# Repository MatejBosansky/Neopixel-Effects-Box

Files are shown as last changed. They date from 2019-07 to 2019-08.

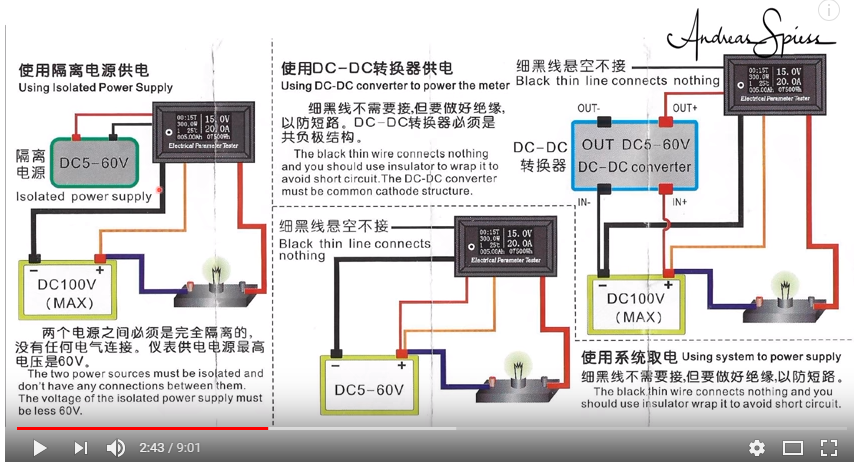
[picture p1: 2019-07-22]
docs/voltmeter wiring.bmp

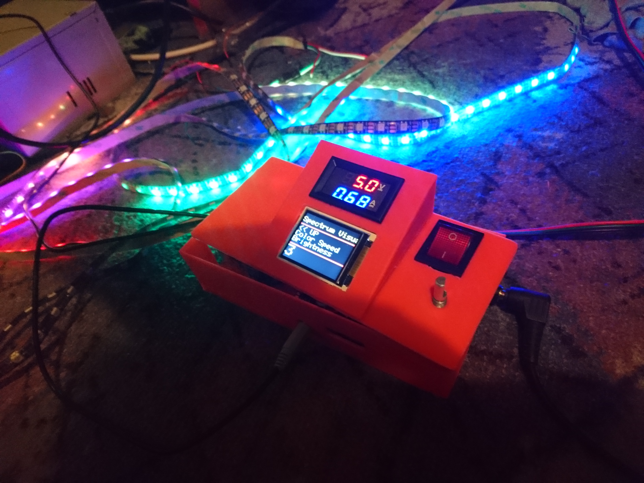
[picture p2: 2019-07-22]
docs/photos/image-20180716_222726.jpg

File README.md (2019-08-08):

# Neopixel Effects Box
Control predefined effects of your attached neopixel(ws2812b) led strip. To get brief overview how it looks like and what do you need, check:
- [Wiring scheme](https://github.com/MatejBosansky/Neopixel-Effects-Box/blob/master/docs/Scheme_bb.pdf).
- Video:

Youtube Video (http://www.youtube.com/watch?v=JeZSuh0Q6hs "Youtube Video")

## Features
- Power supply can be provided via any standard DC adapter like laptop charger with output rating 4-32V. 
- Configurable length of neopixel strip.
- Predefined 4 effects including sound spectrum visualizer based on your audio input.
- Control current effect and its properties with rotary encoder and LCD display.
- Possible to add your another effects - check notes.

## Hardware
I prepared shopping list for 2 aliexpress sellers to not overload your local post service.
Additionally to soldering iron, AC to DC adapter and neopixel strip you will need:

Basic components - This components you need:
- [Wemos D1 Mini ESP8266 Development board](http://www.aliexpress.com/item/32674463823.html).
- [DC-DC Step down converter with proper current rating](https://www.aliexpress.com/item/32821840536.html). Output DC must be adjustable to 5V.
- [ST7735S TFT LCD Display module](http://www.aliexpress.com/item/2055099048.html).
- [Rotary encoder](http://www.aliexpress.com/item/32224563961.html).
- [Mini digital voltmeter](http://www.aliexpress.com/item/32813014220.html).
- [Logic level converter](http://www.aliexpress.com/item/32216841860.html).
- [Audio female 3.5 connector](http://s.click.aliexpress.com/e/cAcySBSY).
- 1000uF +6.3V capacitor.
- 2x 1k Ohm resistor.

This components can be different if you design your own wiring and box.
- [Cable terminal](http://www.aliexpress.com/item/32815936999.html).
- [DC female connector](http://www.aliexpress.com/item/32829667875.html). Choose correct one based on your adapters male connector.
- [Switch](http://s.click.aliexpress.com/e/cFFxSPNA). Must be capable to handle max input current for strip.
- [Prototyping board](http://www.aliexpress.com/item/32224138773.html). 
- Fuse with proper rating.
- Wires.
- 3D printed BOX - check model in repository. This model is designed for components suggested in description.

## Notes
- Take in mind, that one ws2812b pixel can draw 60mA when is fully loaded (brightest white color). Multiply this value by count of your pixels and you have max possible power rating for your components like DC-DC converter, AC-DC adapter, wires, fuse, button.... But in reality real peak consuption for default effects is max 1/4 of this value.
- Recommending in code to define around 70% of max brightness - no too much noticable difference in brightness but significantly less power consuption.
- Code has been initialy developed in original Arduino IDE divided into multiple *ino files. In order to make quick migration to PlatformIO I needed to merge all files content into one main.cpp file.
- If you want to add your own effect, search `//**` code marks to go through guide inside the code.
- Check photos in docs folder to see parts layout on prototype board.
- **Must have project for every makers party!**

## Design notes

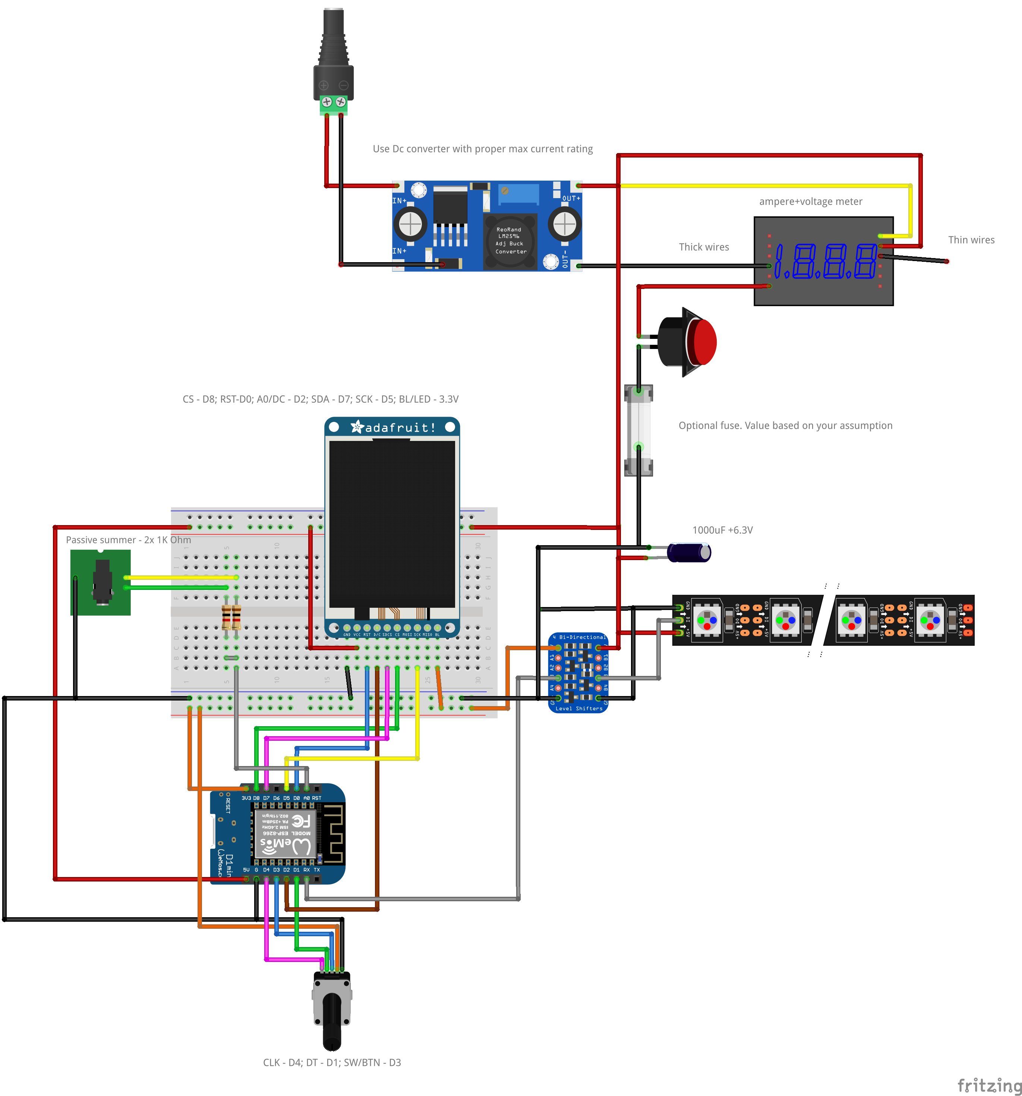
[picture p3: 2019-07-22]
docs/Scheme_bb.png

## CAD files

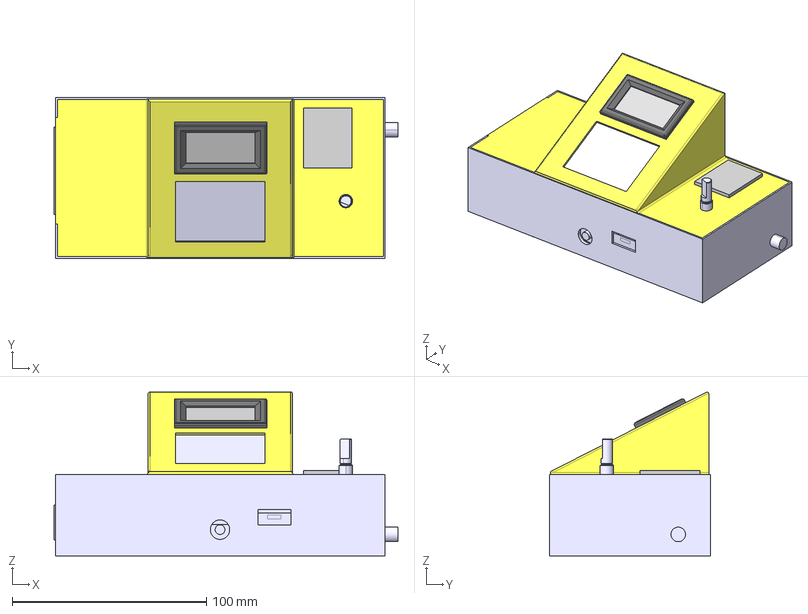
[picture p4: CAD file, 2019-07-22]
Box 3D model/Led Box assy.stp
177.3 x 82.9 x 84.4 mm
Button 20A
DC-DC 15A converter
rotary encoder_chesr_2013_AllCATPart
ST7733
Dc plug
Board
Bottom box
Box top
Mini DC 100V 10A Digital Voltmeter Ammeter v2

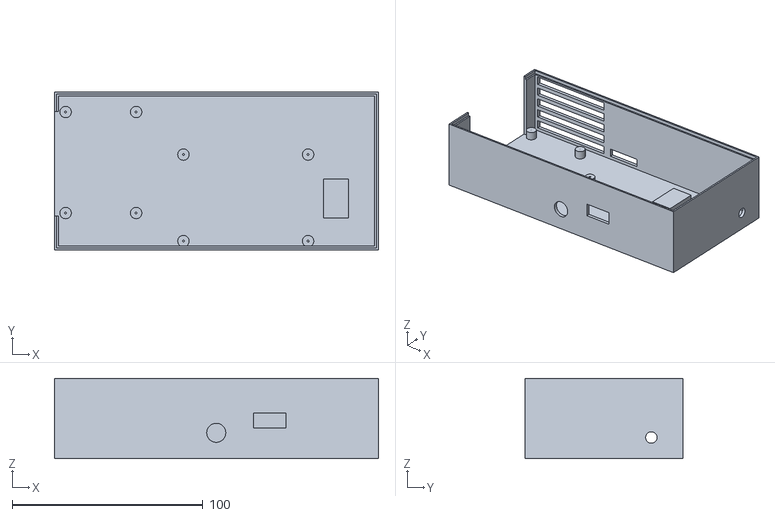
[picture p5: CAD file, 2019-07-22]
Box 3D model/Bottom Box.stl
170.0 x 82.9 x 42.0

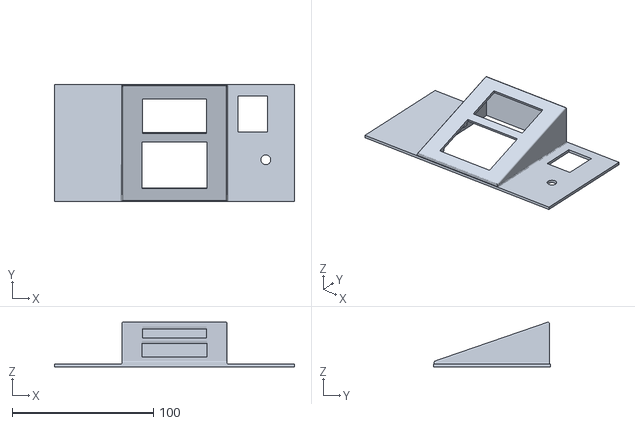
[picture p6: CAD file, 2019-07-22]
Box 3D model/Box top.stl
170.0 x 82.9 x 31.6

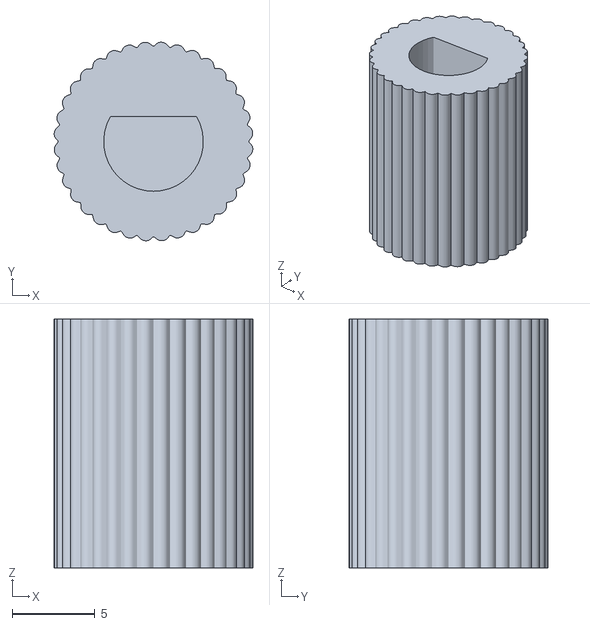
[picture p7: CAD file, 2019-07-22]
Box 3D model/Knob.stl
12.0 x 12.0 x 15.0

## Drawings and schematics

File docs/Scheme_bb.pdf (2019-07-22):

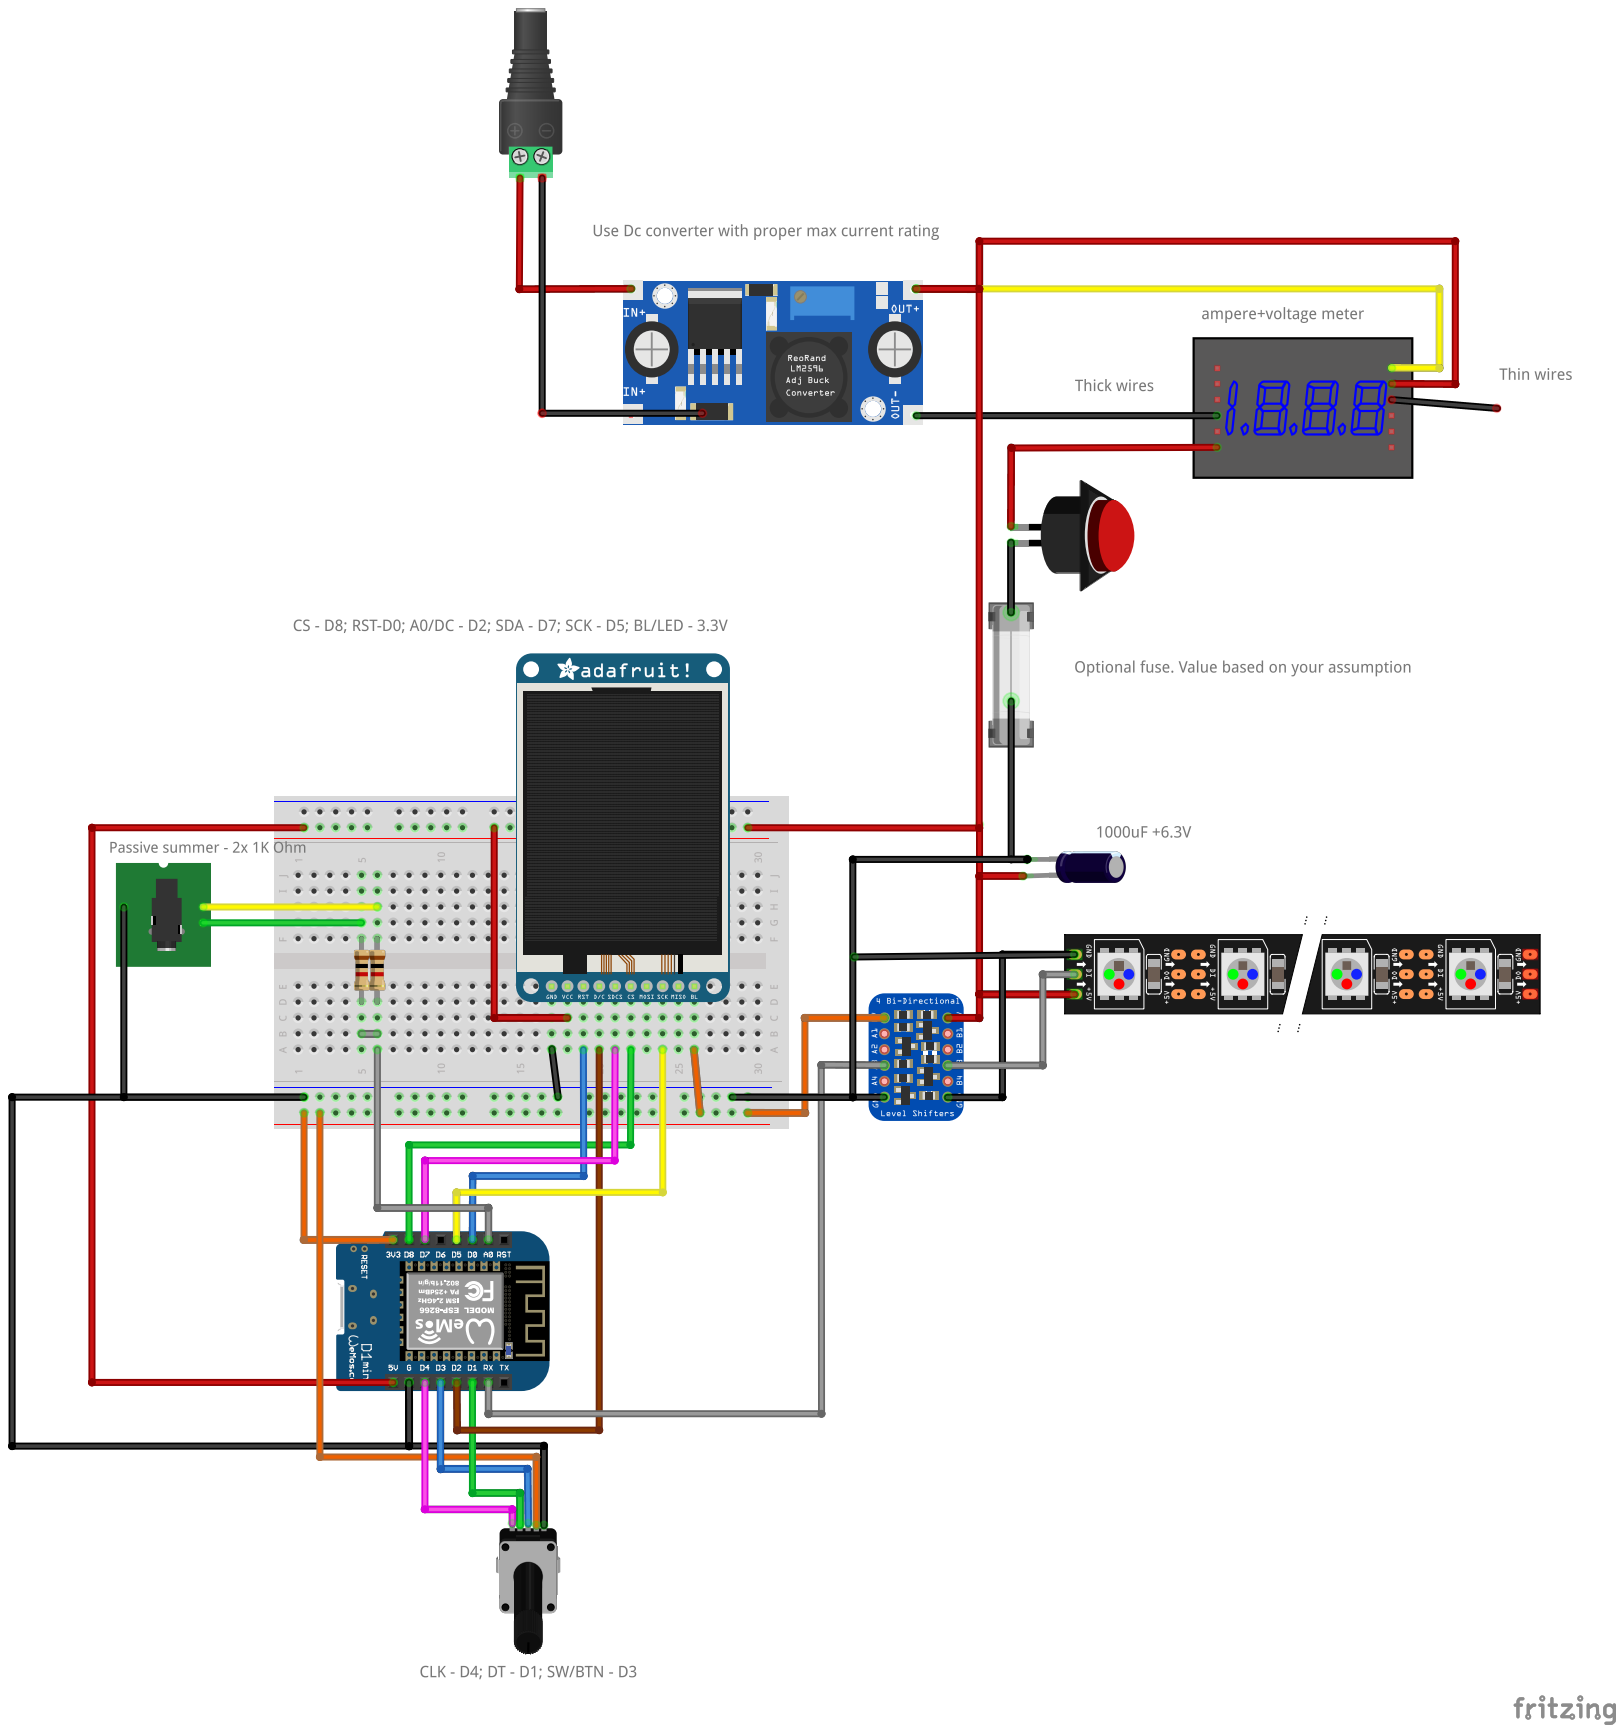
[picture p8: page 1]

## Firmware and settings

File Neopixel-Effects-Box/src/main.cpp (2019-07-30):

#ifdef __AVR__
#include <avr/power.h>
#endif
#include <Arduino.h>
#define FASTLED_ALLOW_INTERRUPTS 0
#include <Adafruit_GFX.h>    // Core graphics library
#include <Adafruit_ST7735.h> // Hardware-specific library
#include <SPI.h>
#include "arduinoFFT.h"
#include <Encoder.h>
#include <FastLED.h>
//https://github.com/FastLED/FastLED/wiki/Pixel-reference


//strip define
#define PIN RX //Neopixel data pin num
#define PixNum 295 //Count of pixels
#define MaxBright 150 // 1 - 255 in order to optimize power consuption you can reduce max possible brightness

//Define Audion analog reader pin
#define AudioPin A0

//Rotary encoder define
#define RotaryCLK D4 //clk
#define RotaryDT D1 //DT
#define RotaryBTN D3 //MS
Encoder myEnc(RotaryCLK, RotaryDT);

//Display define
#define TFT_CS     D8
#define TFT_RST    D0  // you can also connect this to the Arduino reset
// in which case, set this #define pin to 0!
#define TFT_DC     D2
// Option 1 (recommended): must use the hardware SPI pins
// (for UNO thats sclk = 13 and sid = 11) and pin 10 must be
// an output. This is much faster - also required if you want
// to use the microSD card (see the image drawing example)



void RotaryPush();
void RotaryChangeCheck();

Adafruit_ST7735 tft = Adafruit_ST7735(TFT_CS, TFT_DC, TFT_RST);


int MaxBrightness = MaxBright; //* define on start
int MaxStripLength = PixNum; //* define on start
long Change = 0; //flag for interrupt trigger /0 No change /-1 Rotary down / +1 rotary up / 2 button

CRGBArray<PixNum> np;

int Zero = 0; //do not remove this


//----------------------------------------MENU

class Param
{
private:
	int max;
	int min;
	int step;
public:
	int val;
	String name;
	void SetVals(String name, int val, int min, int max, int step) {
		this->name = name;
		this->val = val;
		this->min = min;
		this->max = max;
		this->step = step;
	}
	void StepChange(int type) {
		//type : +1 - increment, -1 vice versa
		if (type == 1) {
			if (val + step <= max)
				val += step;
		}
		else if (type == -1) {
			if (val - step >= min)
				val -= step;
		}
	};
};

struct Effect
{
public:
	String name;
	int ParametersNum;
	Param Parameters[8]; //**4. Extend maximal number of paramaters if needed (if want to have definable more parameters as is already set)
};

#define NumberOfEffects 4 //**1. increment value if you want to add new effect 
struct MenuStruct {
	int EffectsNum = NumberOfEffects;
	Effect Effects[NumberOfEffects];
};

//actual menu position object. 
struct MenuPos {
	int CurrentEffect=2;
	int CurrentParameter=1;
	int Cursor = 0; //0-Effect, 1-Parameter, 2-InsideParameter
};
//In this object are stored all values about actual effect, actual parameter, menu position...
MenuPos MenuPosition;
MenuStruct Menu;



int SetMenu()
{
	//**2. add new effect name - new index value of your effect - x - will be used when calling values from Menu.Effects[x]
	Serial.begin(115200);
	Menu.Effects[0].name = "Snakes";
	Menu.Effects[1].name = "Sparkles";
	Menu.Effects[2].name = "Bouncing Snakes";
	Menu.Effects[3].name = "Spectrum Visual";
	Menu.EffectsNum = NumberOfEffects;
	

	//Definning
	Menu.Effects[0].Parameters[0].SetVals("<< UP", 1, 1, 1, 1);
	Menu.Effects[0].Parameters[1].SetVals("Loop time[ms]", 50, 0, 1000, 5); //Name, Default value, Minimal value, Maximal value, Step value
	Menu.Effects[0].Parameters[2].SetVals("Brightness", 60, 1, MaxBrightness, 3);
	Menu.Effects[0].Parameters[3].SetVals("Strip Length", MaxStripLength, 1, MaxStripLength, 1);
	Menu.Effects[0].Parameters[4].SetVals("Snake Length", 10, 1, MaxStripLength - 1, 1);
	Menu.Effects[0].Parameters[5].SetVals("Snake Gap", 50, 1, MaxStripLength - 1, 1);
	Menu.Effects[0].ParametersNum = 5;

	Menu.Effects[1].Parameters[0].SetVals("<< UP", 1, 1, 1, 1);
	Menu.Effects[1].Parameters[1].SetVals("Loop time[ms]", 50, 0, 1000, 5); //Name, Default value, Minimal value, Maximal value, Step value
	Menu.Effects[1].Parameters[2].SetVals("Brightness", 50, 1, MaxBrightness, 3);
	Menu.Effects[1].Parameters[3].SetVals("Min Bright", Menu.Effects[1].Parameters[2].val/2, 1, MaxBrightness-1, 3);
	Menu.Effects[1].Parameters[4].SetVals("Strip Length", MaxStripLength - 1, 1, MaxStripLength, 1);
	Menu.Effects[1].Parameters[5].SetVals("Color Num", 3, 1, 11, 1);
	Menu.Effects[1].Parameters[6].SetVals("Change time", 800, 1, 30000, 20);
	Menu.Effects[1].Parameters[7].SetVals("Sparkles Num", MaxStripLength / 2, 1, MaxStripLength - 1, 5);
	Menu.Effects[1].ParametersNum = 7; //-1

	Menu.Effects[2].Parameters[0].SetVals("<< UP",1,1,1,1); 
	Menu.Effects[2].Parameters[1].SetVals("Loop time[ms]", 50, 0, 1000, 5); //Name, Default value, Minimal value, Maximal value, Step value
	Menu.Effects[2].Parameters[2].SetVals("Brightness", 70, 1, MaxBrightness, 3);
	Menu.Effects[2].Parameters[3].SetVals("Strip Length", MaxStripLength, 1, MaxStripLength, 1);
	Menu.Effects[2].Parameters[4].SetVals("Snake Length", 10, 1, MaxStripLength - 1, 1);
	Menu.Effects[2].Parameters[5].SetVals("Snake Count", 3, 1, 9, 1);
	Menu.Effects[2].ParametersNum = 5;

	Menu.Effects[3].Parameters[0].SetVals("<< UP", 1, 1, 1, 1);
	Menu.Effects[3].Parameters[1].SetVals("Color Speed", 3, 0, 100, 1); 
	Menu.Effects[3].Parameters[2].SetVals("Brightness", 70, 1, MaxBrightness, 3); 
	Menu.Effects[3].Parameters[3].SetVals("Strip Length", MaxStripLength, 1, MaxStripLength, 1); 
	Menu.Effects[3].Parameters[4].SetVals("Color Mode", 2, 1, 4, 1);  //how colors are distributed
	Menu.Effects[3].Parameters[5].SetVals("Peak Reducer", 100, 1, 1000, 5);  //good to adjust volume sensitivity
	Menu.Effects[3].Parameters[6].SetVals("Fade Speed", 60, 1, 1000, 5); //how fast band visualisation light fades 
	Menu.Effects[3].ParametersNum = 6;
	
	//**3. Like all effects in this function, define all parameters - values which want to be able change durring the run. 
	//**3. Define also ParametersNum
	//**3. 0 index is always "<< UP" - it is possibility to go on effect selection in menu
	//**3. actual value of parameter is as public in Menu.Effects[x].Parameters[y].val
	//**3.  x-index of your effect, y - array ID of your parameter

}

//in this function is processed every rotary push/change + updated display
//as argument using Change variable -1 rotary down, 1 rotary up, 2 push
//also considering MenuPosition value
void PrintDisplay() {
	uint16 GreyColor = 0xC618;
	Serial.print("Running Change ");
	Serial.println(Change);
	
	//on button push
	if (Change == 2) {
		switch (MenuPosition.Cursor)
		{
		case 2: {
			MenuPosition.Cursor = 1;
			break;
		}
		case 1: {
			if (MenuPosition.CurrentParameter == 0) //If cursor is on "<< UP"
				MenuPosition.Cursor = 0;
			else
				MenuPosition.Cursor = 2;
			break;
		}
		case 0: {
			MenuPosition.Cursor = 1;
			break;
		}
		default:
			Serial.println("Problem with Cursor");
			Serial.println(MenuPosition.Cursor);
			break;
		}
		
	}

	if (Change == 1 || Change == -1) {
		if (MenuPosition.Cursor == 2) {
				if (MenuPosition.CurrentParameter != -1)
					Menu.Effects[MenuPosition.CurrentEffect].Parameters[MenuPosition.CurrentParameter].StepChange(Change); //decrement
		}

		if (MenuPosition.Cursor == 1) {
			int ProposedChange = MenuPosition.CurrentParameter + Change;
			Serial.println(ProposedChange);
			if ((ProposedChange <= Menu.Effects[MenuPosition.CurrentEffect].ParametersNum) && (ProposedChange >= 0)) {
				MenuPosition.CurrentParameter = ProposedChange;
			}
		}
			if (MenuPosition.Cursor == 0) {
				int ProposedChange = MenuPosition.CurrentEffect + Change;
				if ((ProposedChange < Menu.EffectsNum) && (ProposedChange >= 0)) {
					MenuPosition.CurrentEffect = ProposedChange;
			}
		}
	}

	tft.setCursor(0, 10);
	tft.setTextSize(2);
	tft.setTextColor(GreyColor);

	//If button is pushed, change everything
	int ChangeDisplayLevel = 0;
	if (Change != 2) { ChangeDisplayLevel = MenuPosition.Cursor; };

	switch (ChangeDisplayLevel)
	{
	case 0: {
		if (MenuPosition.Cursor == 0)
			tft.setTextColor(ST7735_YELLOW);
		else tft.setTextColor(GreyColor);
		tft.setCursor(0, 10);
		tft.fillRect(0, 1, 160, 29, ST7735_BLACK);
		tft.println(Menu.Effects[MenuPosition.CurrentEffect].name);
	}
	case 1: {
		tft.setCursor(0, 36);
		tft.fillRect(0, 35, 160, 52, ST7735_BLACK);
		tft.setTextColor(GreyColor);
		if (MenuPosition.CurrentParameter > 0)
			tft.println(Menu.Effects[MenuPosition.CurrentEffect].Parameters[MenuPosition.CurrentParameter-1].name);
		else
			tft.println(" ");
		if (MenuPosition.Cursor == 1) {
			tft.setTextColor(ST7735_YELLOW);
			tft.fillTriangle(152, 61, 157, 56, 157, 66, ST7735_BLUE);}
		else tft.setTextColor(GreyColor);
		tft.println(Menu.Effects[MenuPosition.CurrentEffect].Parameters[MenuPosition.CurrentParameter].name);
		tft.setTextColor(GreyColor);
		if (MenuPosition.CurrentParameter < Menu.Effects[MenuPosition.CurrentEffect].ParametersNum)
			tft.println(Menu.Effects[MenuPosition.CurrentEffect].Parameters[MenuPosition.CurrentParameter+1].name);

	}
	case 2: {
		if (MenuPosition.Cursor == 2)
			tft.setTextColor(ST7735_YELLOW);
		else tft.setTextColor(GreyColor);
		tft.setCursor(0, 94);
		tft.fillRect(0, 93, 160, 35, ST7735_BLACK);
		tft.setTextSize(4);
		tft.println(Menu.Effects[MenuPosition.CurrentEffect].Parameters[MenuPosition.CurrentParameter].val);
	}
	default:
		break;
	}

	myEnc.write(0);
}


//--------------------------------Snakes Effect



float CurrentSnakeColor[3];
int *SnakeValues = new int[MaxStripLength]; //calculated values for snake to avoid same calculations in every loop, used in both snake effects

void Snakes_SetColor();
void SnakesSet() { //**5. Define setup function for effect same like here
	FastLED.clear();
	Snakes_SetColor();
	SnakeValues[0] = 0;
}


void DefineSnakeValues(int Length, int Brightness, int* Snake); 
void SnakesLoop() { //**5. define loop function like here
	
int counter = 0;
int SnakeCounter = 1;
int GapCounter = 0;

	while (MenuPosition.CurrentEffect == 0) { //**6. code inside loop function must be wrapped by while loop watching current effect
		memmove(&np[1], &np[0], (Menu.Effects[0].Parameters[3].val - 1) * sizeof(CRGB));

		//Checking current length and Brightness, if a same are used in SnakeValues
		if ((SnakeValues[0] != Menu.Effects[0].Parameters[4].val) || (SnakeValues[1] != Menu.Effects[0].Parameters[2].val)) {
			DefineSnakeValues(Menu.Effects[0].Parameters[4].val, Menu.Effects[0].Parameters[2].val, SnakeValues);
		}


		if (GapCounter >= Menu.Effects[0].Parameters[5].val) {
			GapCounter = 0;
			SnakeCounter = 1;
			np[0].setRGB(0, 0, 0);
		}
		else if (GapCounter >= 1) {
			np[0].setRGB(0, 0, 0);
			GapCounter++;
		};

		if (SnakeCounter == 1) {
			Snakes_SetColor();
			np[0].setRGB(CurrentSnakeColor[0]*SnakeValues[1], CurrentSnakeColor[1]*SnakeValues[1], CurrentSnakeColor[2]*SnakeValues[1]);
			SnakeCounter++;
		}
		else if ((SnakeCounter <= Menu.Effects[0].Parameters[4].val) && (SnakeCounter > 1)) {
			np[0].setRGB(CurrentSnakeColor[0] * SnakeValues[SnakeCounter], CurrentSnakeColor[1] * SnakeValues[SnakeCounter], CurrentSnakeColor[2] * SnakeValues[SnakeCounter]);
			SnakeCounter++;
		}
		else if (SnakeCounter > Menu.Effects[0].Parameters[4].val) {
			np[0].setRGB(0, 0, 0);
			SnakeCounter = 0;
			GapCounter = 1;
		};

		FastLED.show();
		
		RotaryChangeCheck();//**7. Add this before end of while loop, to trigger rotary encoder change flag

		
		delay(Menu.Effects[0].Parameters[1].val);
	}
}


void Snakes_SetColor() {
	CurrentSnakeColor[0] = random(1,11)*0.1; CurrentSnakeColor[1] = random(1, 11)*0.1; CurrentSnakeColor[2] = random(1, 11)*0.1;
}

double CalculateFadeModifier(int NumOfPixels);
void DefineSnakeValues(int Length, int Brightness, int* Snake) {
	double FadeModifier = CalculateFadeModifier(Length);
	double CurrentValue = Brightness;
	Snake[0] = Length;
	Snake[1] = Brightness;
	for (int i = 2; i <= Length; i++) {
		CurrentValue = CurrentValue * FadeModifier;
		int val = int(CurrentValue);
		Snake[i] = val;
	}


}


//magic function to calculate constant number. It is for cumulative multiply value from maximal brightness value_
//of snake until end of length of snake based on its length
//Reason for this is to calculate snake pixels brightness values let transition looks smooth, because linear decrease of brightness values doesnt look good
double CalculateFadeModifier(int NumOfPixels) {
	if (NumOfPixels < 46) {
		//Magic formula with bulgarian constants 
		return 0.1222*log(NumOfPixels) + 0.4868;
	}
	//increasing is now linear instead of logarithmic with molvanian constant
	else if ((NumOfPixels <101) && (NumOfPixels >= 46)) {
		return 0.95 + ((NumOfPixels - 45)*0.000545454);
	}
	else if ((NumOfPixels < 201) && (NumOfPixels >= 101)) {
		return 0.98 + ((NumOfPixels - 100)*0.0001);
	}
	else {
		return 0.99;
	}

}


//---------------------------------Snakes 2



class BouncingSnake {
public:
	bool Direction = true; //True - from 0 to End
	float Position = 0;
	float Speed = 1;
	int &length = Menu.Effects[2].Parameters[4].val;
	float Color[3]; // modifier of current brightness -> x*Brightness

	void Inc() {
		if (Direction)
			Position += Speed;
		else
			Position -= Speed;
		if ((int(Position) >= Menu.Effects[2].Parameters[3].val) || (int(Position) <= 0)) {
			Direction = !Direction;
		}
	};
};



BouncingSnake s[9];

void SetBouncingSnakes() {
	FastLED.clear();
	SnakeValues[0] = 0;


	s[0].Position = 50; s[0].Speed = 0.8; 
	s[0].Color[0] = 1; s[0].Color[1] = 0.5; s[0].Color[2] = 0;
	s[1].Position = 20; s[1].Speed = 1.5; 
	s[1].Color[0] = 0; s[1].Color[1] = 1; s[1].Color[2] = 0;
	s[2].Position = 1; s[2].Speed = 1;
	s[2].Color[0] = 0; s[2].Color[1] = 0; s[2].Color[2] = 1;
	s[3].Position = 10; s[3].Speed = 0.7;
	s[3].Color[0] = 0; s[3].Color[1] = 1; s[3].Color[2] = 1;
	s[4].Position = 30; s[4].Speed = 1.2; 
	s[4].Color[0] = 1; s[4].Color[1] = 1; s[4].Color[2] = 0;
	s[5].Position = 20; s[5].Speed = 1.1; 
	s[5].Color[0] = 1; s[5].Color[1] = 0; s[5].Color[2] = 1;
	s[6].Position = 10; s[6].Speed = 0.9; 
	s[6].Color[0] = 0.5; s[6].Color[1] = 1; s[6].Color[2] = 0.5;
	s[7].Position = 5; s[7].Speed = 0.95; 
	s[7].Color[0] = 0.8; s[7].Color[1] = 0.5; s[7].Color[2] = 0.2;
	s[8].Position = 15; s[8].Speed = 1.35; 
	s[8].Color[0] = 0.5; s[8].Color[1] = 0.9; s[8].Color[2] = 0.2;
}



void BouncingSnakesLoop() {

	while (MenuPosition.CurrentEffect == 2) {
		FastLED.clearData();
		//Checking current length and Brightness, if a same are used in SnakeValues (detecting changes in settings)
		if ((SnakeValues[0] != Menu.Effects[2].Parameters[4].val) || (SnakeValues[1] != Menu.Effects[2].Parameters[2].val)) {
			DefineSnakeValues(Menu.Effects[2].Parameters[4].val, Menu.Effects[2].Parameters[2].val, SnakeValues);
		}

		for (int j = 0; j < Menu.Effects[2].Parameters[5].val; j++) {
			s[j].Inc();
			int pos = int(s[j].Position);
			if (s[j].Direction) {
				for (int i = 1; i < Menu.Effects[2].Parameters[4].val + 1; i++) {
					if ((pos - i) < 0) {
						np[pos + i].setRGB(np[pos + i][0] + s[j].Color[0]*SnakeValues[i], np[pos + i][1] + s[j].Color[1] * SnakeValues[i], np[pos + i][2] + s[j].Color[2] * SnakeValues[i]);
					}
					else {
						np[pos - i].setRGB(np[pos - i][0] + s[j].Color[0] * SnakeValues[i], np[pos - i][1] + s[j].Color[1] * SnakeValues[i], np[pos - i][2] + s[j].Color[2] * SnakeValues[i]);
					}
				}
			}
			else {
				for (int i = 1; i < Menu.Effects[2].Parameters[4].val + 1; i++) {
					if ((pos + i) > Menu.Effects[2].Parameters[3].val)
					{
						np[pos - i].setRGB(np[pos - i][0] + s[j].Color[0] * SnakeValues[i], np[pos - i][1] + s[j].Color[1] * SnakeValues[i], np[pos - i][2] + s[j].Color[2] * SnakeValues[i]);
					}
					else
					{
						np[pos + i].setRGB(np[pos + i][0] + s[j].Color[0] * SnakeValues[i], np[pos + i][1] + s[j].Color[1] * SnakeValues[i], np[pos + i][2] + s[j].Color[2] * SnakeValues[i]);
					}
				}
			}
		}
		FastLED.show();
		RotaryChangeCheck();
		delay(Menu.Effects[2].Parameters[1].val);
	}

}



//-----------------------------------Sparkles


#define FadeByFactor_Sparkles 1 //(x/255*100)
#define LoopToCheckCount 2


CRGB SetPixel(int Index) {
	CRGB pixel;
	int Num = random8(Menu.Effects[1].Parameters[3].val, Menu.Effects[1].Parameters[2].val);
	switch (Index) {
		//case 1: {pixel.setRGB(random8(MinBright, MaxBright), 0, 0); break; }
	case 1: {pixel.setRGB(Num, Num / 2, Num / 3); break; }
	case 2: {pixel.setRGB(Num / 2, Num, Num / 3); break; }
	case 3: {pixel.setRGB(Num / 3, Num / 2, Num); break; }
	case 4: {pixel.setRGB(Num, Num / 2, Num / 3); break; }
	case 5: {pixel.setRGB(Num, Num / 3, Num); break; }
	case 6: {pixel.setRGB(Num / 3, Num, Num); break; }
	case 7: {pixel.setRGB(Num / 2, Num, 0); break; }
	case 8: {pixel.setRGB(Num / 2, 0, Num); break; }
	case 9: {pixel.setRGB(0, Num / 2, Num); break; }
	case 10: {pixel.setRGB(Num, Num / 2, 0); break; }//
	case 11: {pixel.setRGB(Num, 0, Num / 2); break; }
	case 12: {pixel.setRGB(0, Num, Num / 2); break; }
	default: pixel.setRGB(30, 30, 30);
	}
	return pixel;
}

int GetRandBlackPix(CRGB np[]);
int GetRandColoredPix(CRGB np[]);
int GetColorPixelNum(CRGB np[]);
void SparklesSet() {

	Serial.println("SparklesSet");
	FastLED.clear();
	for (int i = 0; i < Menu.Effects[1].Parameters[7].val; i++) {
		np[GetRandBlackPix(np)] = SetPixel(1);
	}
}


void SparklesLoop() {
	int CurrentColorIndex = 1;
	bool CreationAllowed = true;
	int ChangeColorCounter = 0;
	int c = 0;

	while (MenuPosition.CurrentEffect == 1){
	np(0, PixNum - 1).fadeToBlackBy(FadeByFactor_Sparkles); //bulk function apply

	//checking pixels function
	if (c++ == LoopToCheckCount) {
		int MissingPixels = Menu.Effects[1].Parameters[7].val - GetColorPixelNum(np);
		if (MissingPixels > 0) {
			abs(MissingPixels);
			for (int j = 0; j < MissingPixels; j++)
				np[GetRandBlackPix(np)] = SetPixel(CurrentColorIndex);
		}

		c = 0;
	};

	if (ChangeColorCounter++ >= Menu.Effects[1].Parameters[6].val) {
		if (CurrentColorIndex >= Menu.Effects[1].Parameters[5].val)
			CurrentColorIndex = 1;
		else
		{
			CurrentColorIndex++;
		}
		ChangeColorCounter = 0;
	};
	FastLED.show();
	RotaryChangeCheck();
	delay(Menu.Effects[1].Parameters[1].val);
	}

}

int GetRandBlackPix(CRGB np[]) {
	while (1) {
		int Pix = random(Menu.Effects[1].Parameters[4].val);
		if (!(np[Pix])) {
			return Pix;
		}
	}
};

int GetRandColoredPix(CRGB np[]) {
	while (1) {
		int Pix = random(Menu.Effects[1].Parameters[7].val);
		if (np[Pix]) {
			return Pix;
		}
	}
};

int GetColorPixelNum(CRGB np[]) {
	int c = 0;
	for (int i = 0; i < Menu.Effects[1].Parameters[4].val; i++) {
		if (np[i]) {
			c++;
		}
	}
	return c;
}

//---------------------------------Spectrum Vis


#define Num_Bands 7
#define SpeedDivider 10.0

class BandData {
public:
	int LowerFreq; //on 256 samle rate, 1 represents 25Hz
	int UpperFreq; //on 256 samle rate, 1 represents 25Hz
	int HSVColor;
	double ValueMultiplier; //Some bands have all the time lower values, for better look I increased their value
	int ActualValue;
	void BandDataSet(int LowerFreq, int UpperFreq, int HSVColor, double ValueMultiplier) {
		this->LowerFreq = LowerFreq;
		this->UpperFreq = UpperFreq;
		this->HSVColor = HSVColor;
		this->ValueMultiplier = ValueMultiplier;
		ActualValue = 0;
	};
	void SetVal(int val) {

		ActualValue = (ActualValue < int(val*ValueMultiplier)) ? int(val*ValueMultiplier) : ActualValue;
	}

};
BandData Bands[Num_Bands];

// https://github.com/kosme/arduinoFFT, in IDE, Sketch, Include Library, Manage Library, then search for FFT
arduinoFFT FFT = arduinoFFT();

#define SAMPLES 256             
#define SAMPLING_FREQUENCY 5000 
#define amplitude 50
unsigned int sampling_period_us;
unsigned long microseconds;
byte peak[] = { 0,0,0,0,0,0,0 };
double vReal[SAMPLES];
double vImag[SAMPLES];
unsigned long newTime, oldTime;

void SpectrumVisualizerSetup() {
	
	FastLED.clear();
	FastLED.show();

	sampling_period_us = round(1000000 * (1.0 / SAMPLING_FREQUENCY));

	//I set frequency band values just to get visualy nice results
	Bands[0].BandDataSet(2, 2, 0, 1); 
	Bands[1].BandDataSet(3, 4, 30, 1);
	Bands[2].BandDataSet(5, 7, 60, 1.4);
	Bands[3].BandDataSet(7, 9, 90, 1.6);
	Bands[4].BandDataSet(10, 13, 120, 1.8);
	Bands[5].BandDataSet(14, 18, 150, 2);
	Bands[6].BandDataSet(19, 128, 180, 2.2);

	FastLED.setBrightness(Menu.Effects[3].Parameters[2].val);
}
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
void loop() {
	//**8. Add new case for your effect array number

	switch (MenuPosition.CurrentEffect)
	{
	case 0: {
		SnakesSet();
		SnakesLoop(); break;}
	case 1:{
		SparklesSet();
		SparklesLoop(); break; }
	case 2:{
		SetBouncingSnakes();
		BouncingSnakesLoop(); break; }
	case 3: {
		SpectrumVisualizerSetup();
		SpectrumVisualizerLoop(); break; }
	//case x:	//**9. Define new case for your effect. Thats all
		   //SetNewEffectFunction();
		   //NewEffectLoop(); 
	default:
		break;
	}
	
}


void RotaryChangeCheck()
{
	Change = myEnc.read();
	if (Change == 0){
		return;
	}
	if (Change == 100){
		Change = 2; // in old way 2 was button, it is like this complicated because at the end of project I changed library for encoder
	}
	//swap values -1 and 1 if you want reverse rotary step
	else{
		if (Change > 0)
			Change = -1; //rotary up

		else if
			(Change < 0)
			Change = 1; //rotary down
}
	
	Serial.print("Rottary changed ");
	Serial.println(Change);
	PrintDisplay();
}

void RotaryPush() {
	myEnc.write(100);
	Serial.println("Button");
}

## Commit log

2019-07-22 Initial upload.
    [Bottom Box.stl, Box top.stl, Knob.stl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]
2019-07-30 Fixed skipping rotary encoder. Added Readme
    [main.cpp]
